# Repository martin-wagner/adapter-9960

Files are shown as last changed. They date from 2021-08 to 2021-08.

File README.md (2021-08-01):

# adapter-9960
Adapter for unobtainable nixie tube driver IC fairchild 9960 ( 960, 996079 ) to SN74414 / K155id1

Contains Kicad project, pdf schematic and gerber files for ordering at your pcb service of choise. Added some other more or less useful stuff to the panel to optimeze for the common 10x10cm pcb manufacturing services. Should fit as direct replacement if pcb is not too densly packed.

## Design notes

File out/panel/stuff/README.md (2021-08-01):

# SMT Breakout Boards

Some small adapter boards to help with prototyping SMT packages on a breadboard.

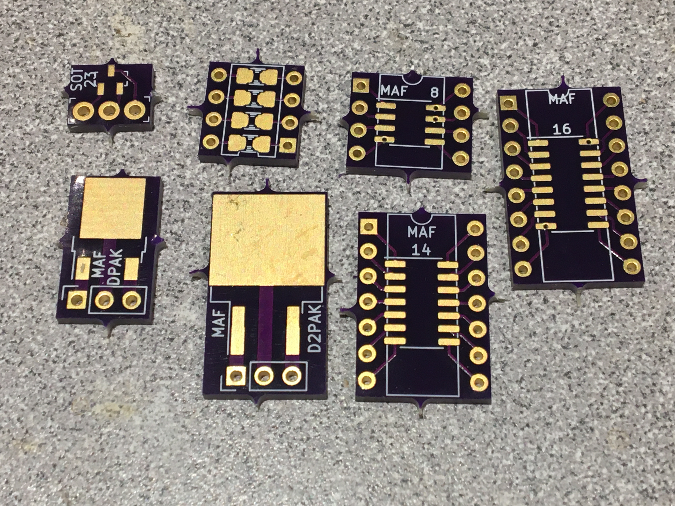
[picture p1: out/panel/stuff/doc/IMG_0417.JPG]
boards


## Design

I used KiCad to draw these.

Usually you would start with a schematic and a symbol and then lay out the PCB.

In this case I just opened the PCBNew application and ad-hoc added the footprints and then drew traces to wire them up.

## Supported Packages

* [SOIC](https://en.wikipedia.org/wiki/Small_outline_integrated_circuit)
  * 8
  * 14
  * 16
* [SOT-23](https://en.wikipedia.org/wiki/Small-outline_transistor)
  * 3
  * 5
* DPAK / [TO-252](https://en.wikipedia.org/wiki/TO-252)
* D2PAK / [TO-263](https://en.wikipedia.org/wiki/TO-263)
* Discrete 0406 / 0603 / 0806 / 1204 packages in a DIP carrier footprint
  * x4
  * x7

I will add more footprints as I need them.

## Fabrication

I Used OSHPark to have these made. Mostly because I don't have a setup to make my own boards.

For convenience, I shared the uploaded board projects:

| Part | Link |
|:-----|:-----|
| SOIC-8  | https://oshpark.com/shared_projects/7HKL5QIy |
| SOIC-14 | https://oshpark.com/shared_projects/QcCbjX4y |
| SOIC-16 | https://oshpark.com/shared_projects/uA6pM7Gf |
| SOT-23  | https://oshpark.com/shared_projects/ge0wqWtr |
| SOT23-5 | https://oshpark.com/shared_projects/e4J13SY4 |
| SMD-6 | https://oshpark.com/shared_projects/h2nZ3u9U |
| TO-252 (DPAK) | https://oshpark.com/shared_projects/cjtZqxyG |
| TO-263 (D2PAK) | https://oshpark.com/shared_projects/tPH46DG8 |
| 0406/0603/0806/1204 x4 | https://oshpark.com/shared_projects/MdGxr2ob |
| 0406/0603/0806/1204 x7 | https://oshpark.com/shared_projects/SLZF8xvz |

> I am not affiliated by or sponsored by OSHPark.
> I just am really happy with the kind of service they provide.

## Assembly

These steps assume you have

* A fine point soldering iron
* Fine electronic solder - I have 22 gauge
* Solder flux.

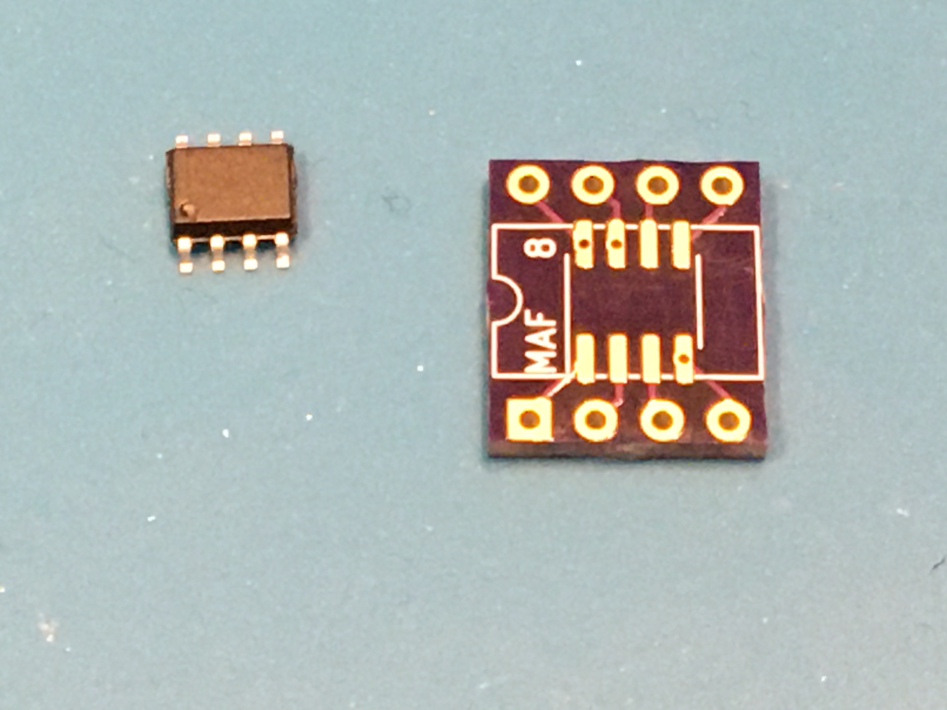
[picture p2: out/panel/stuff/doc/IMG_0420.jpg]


Start by soldering the SMT device to the PCB

* Use as fine of a tip of a soldering iron as you can

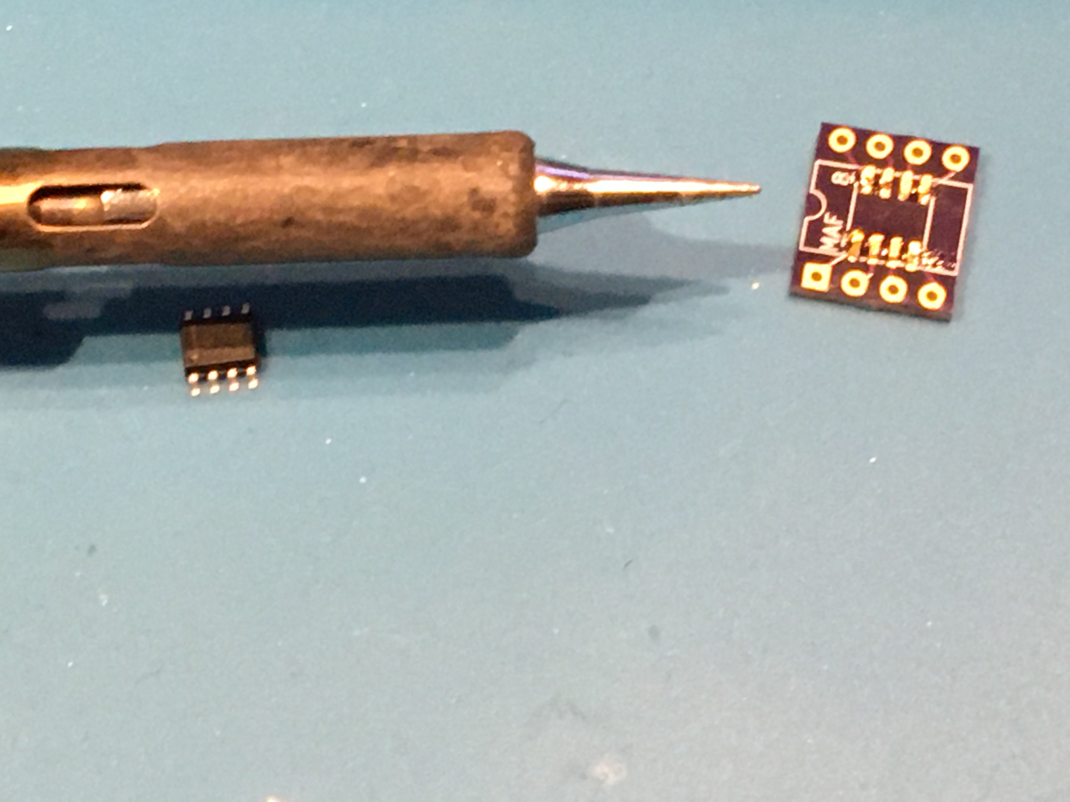
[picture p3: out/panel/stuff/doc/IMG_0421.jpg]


> I have a hot air solder station. I use a fine point solder iron here, as this is more likely what most people would have.

* Use a bit of solder flux across all the pads.

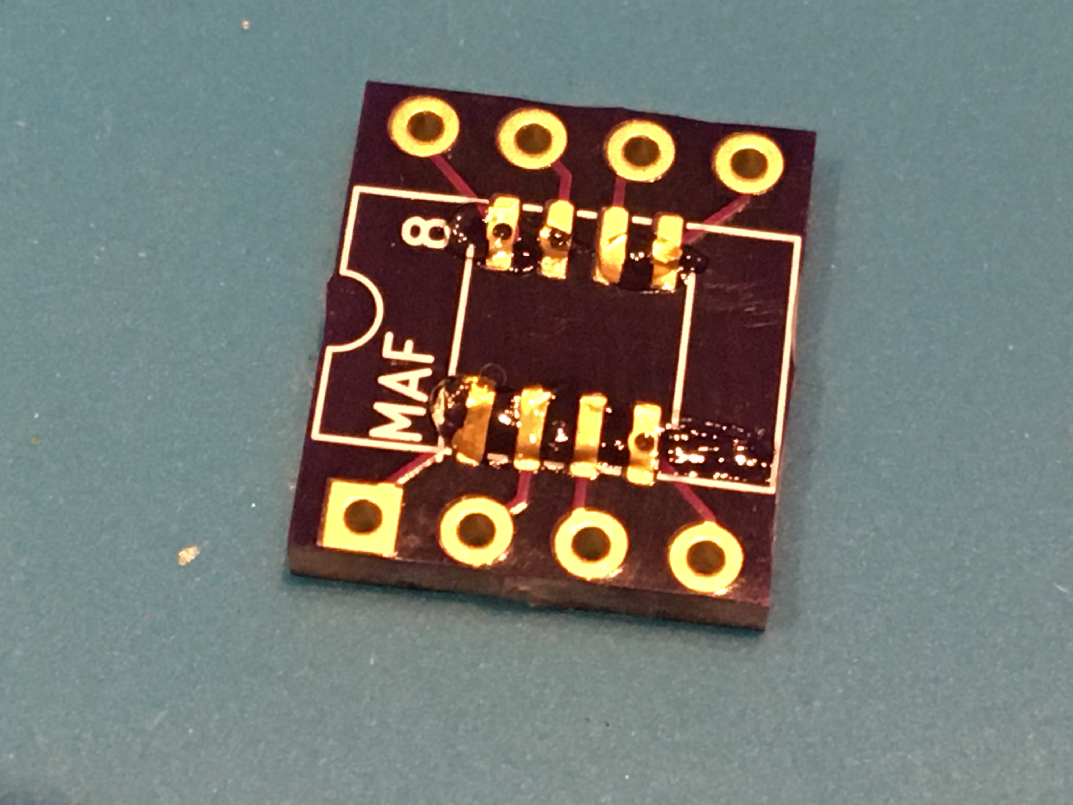
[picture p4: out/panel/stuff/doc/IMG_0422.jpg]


* Orient the package over the pads

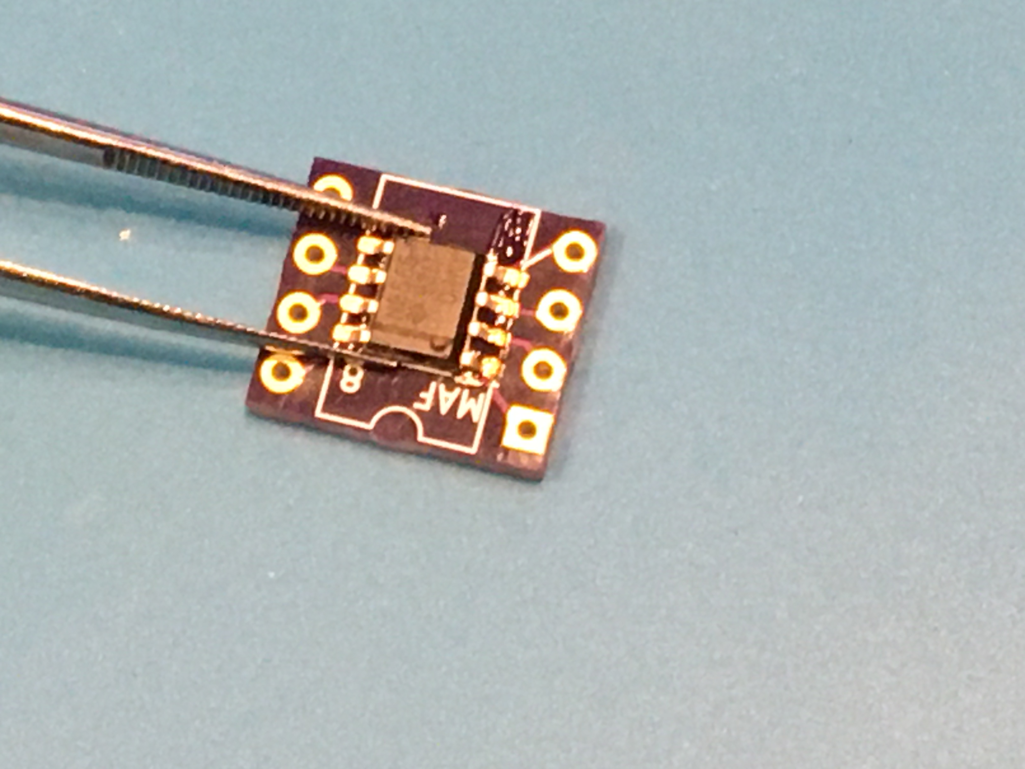
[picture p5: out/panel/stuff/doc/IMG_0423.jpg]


> I like to use a pair of tweezers

* Tack one of the pins with a bit of solder loosely.

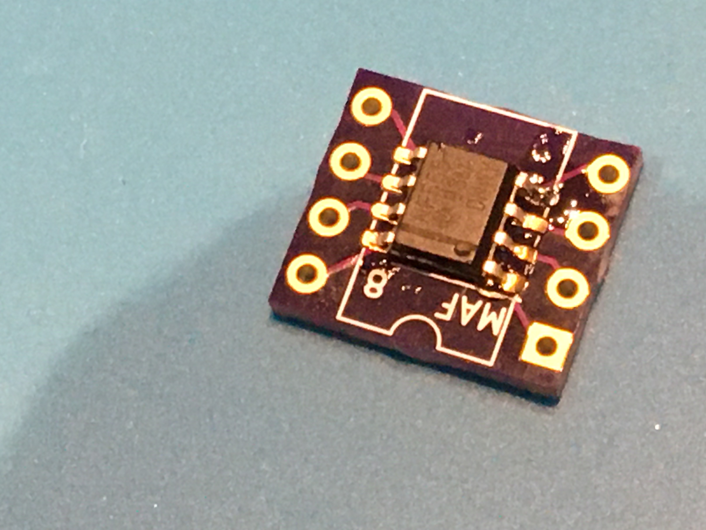
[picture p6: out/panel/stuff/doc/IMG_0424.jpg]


* Make sure the package is still lined up. If it is not. Reheat the pad we tacked it with, use tweezers to nudge the package until it is aligned.

> This is the hard part and takes practise.

* Drag a bit of solder across the pins

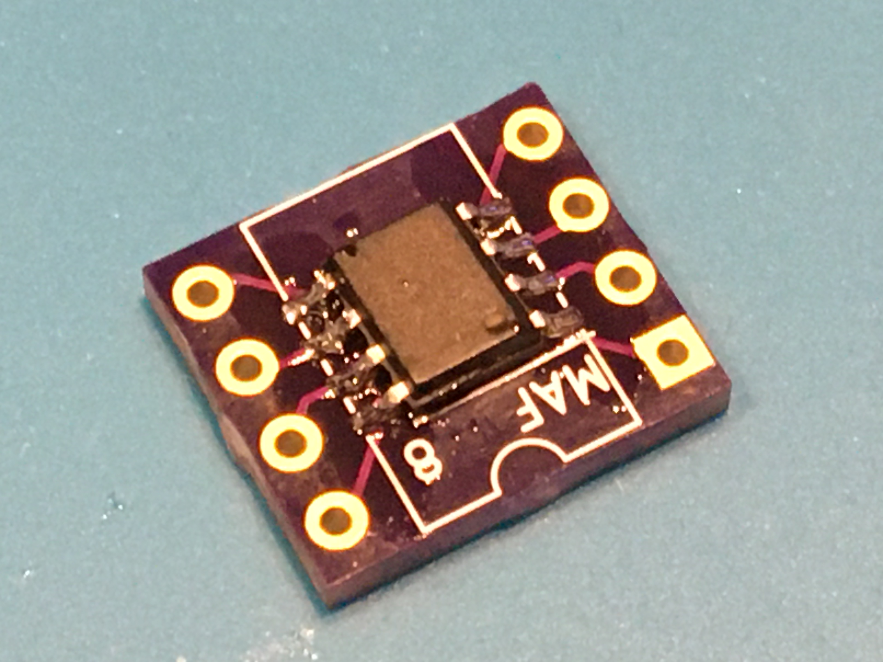
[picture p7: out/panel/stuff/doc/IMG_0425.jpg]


> This part is fun. The solder mask prevents the solder from sticking between the pads. The flux helps the solder to flow evenly over each pin.
> We want to use as little solder as possible here.

* Clean the extra solder flux off with a bit of rubbing alcohol and a q-tip or small sponge.

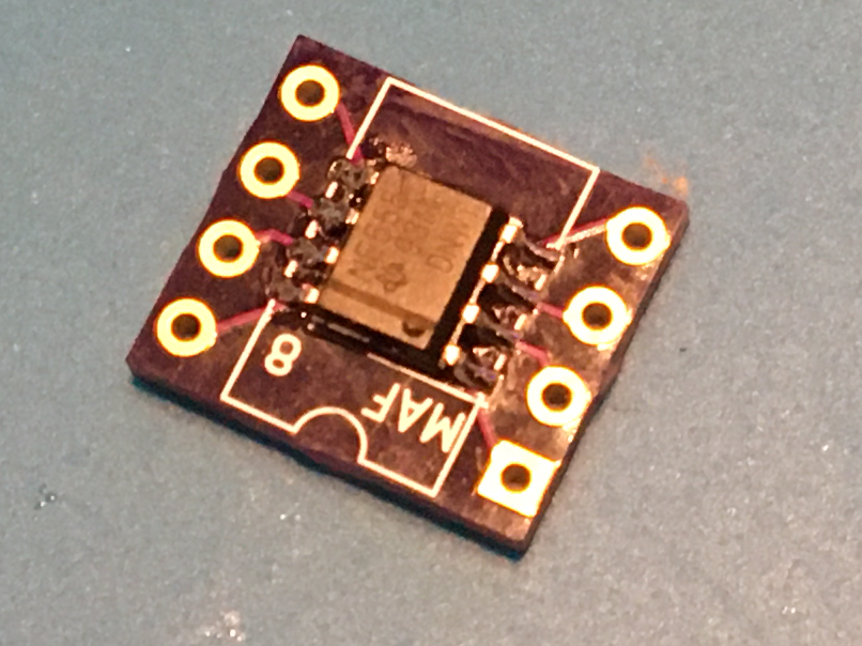
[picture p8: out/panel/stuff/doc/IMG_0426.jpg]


> If your device is static sensitive, work on a grounded or ESD safe surface.

* (Optional) : Where applicable, if you would like a decoupling capacitor, solder the 0603 package capacitor to the back

* Cut stock pin headers as needed.

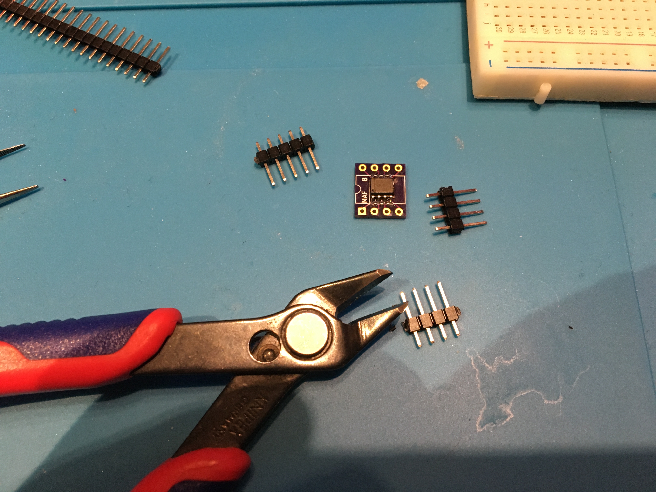
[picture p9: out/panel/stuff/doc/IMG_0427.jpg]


* Dry fit place the headers into the holes. Test alignment with a proto board or breadboard.

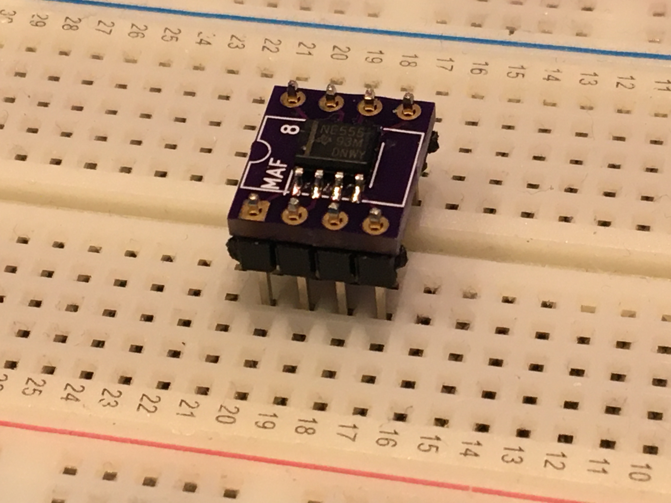
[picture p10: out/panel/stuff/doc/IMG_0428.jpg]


> But do not solder with a lot of heat on the breadboard, it migh melt the breadboard socket guides.

* Solder the pins all the way.

And then the final result:

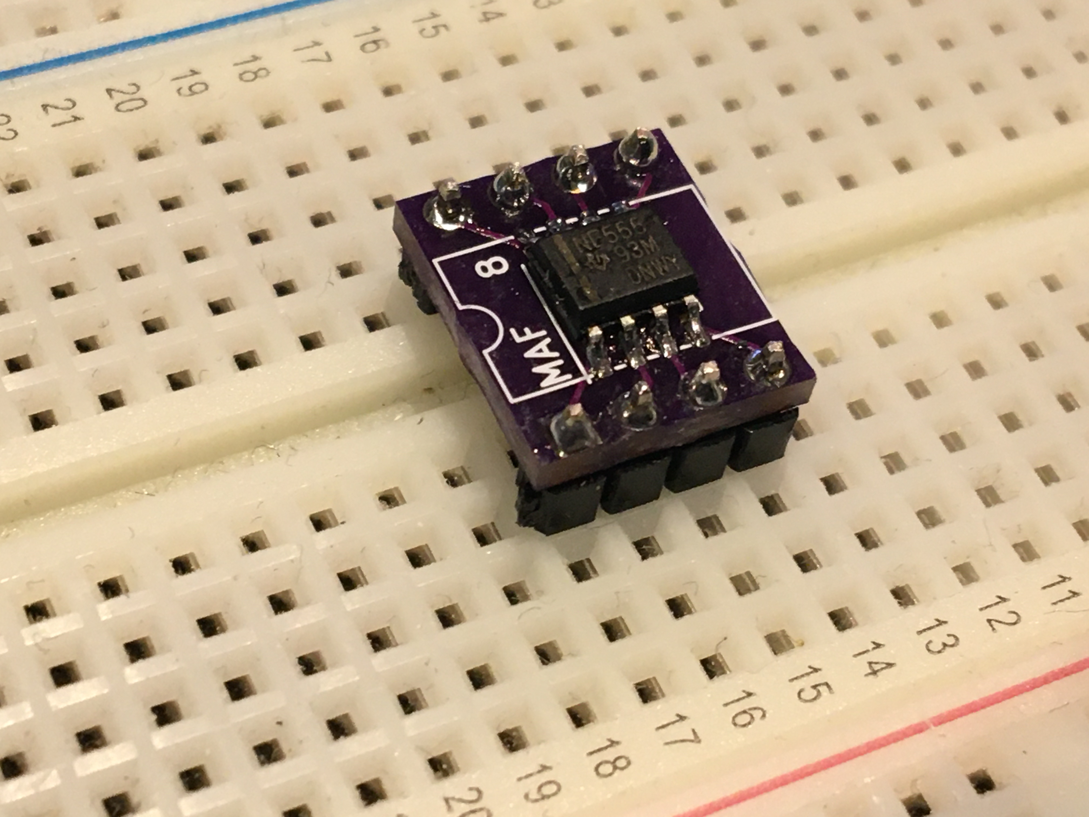
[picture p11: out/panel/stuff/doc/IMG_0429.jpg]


It is the similar idea for the other packages, just with more or different pins really.

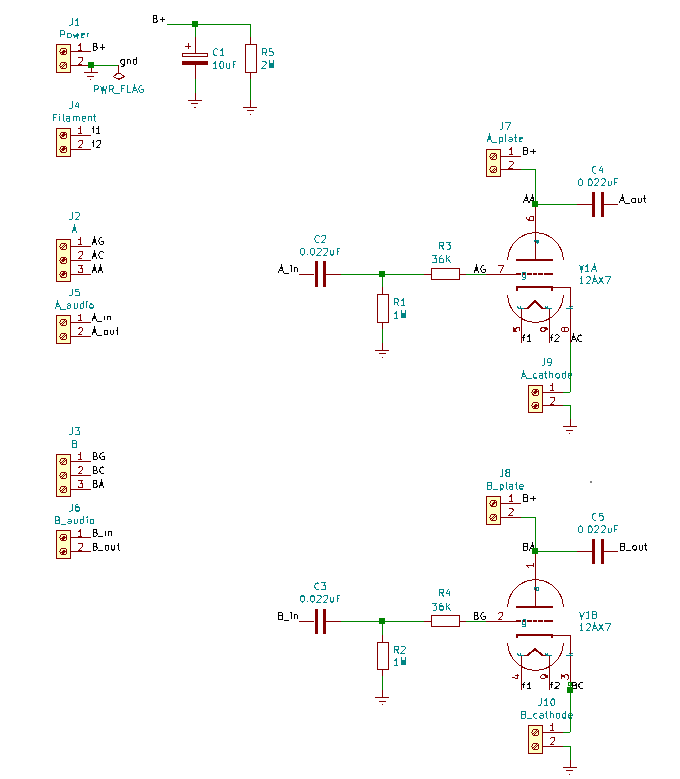
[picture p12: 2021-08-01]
out/panel/stuff/VT9-PT/schematic_v1.png

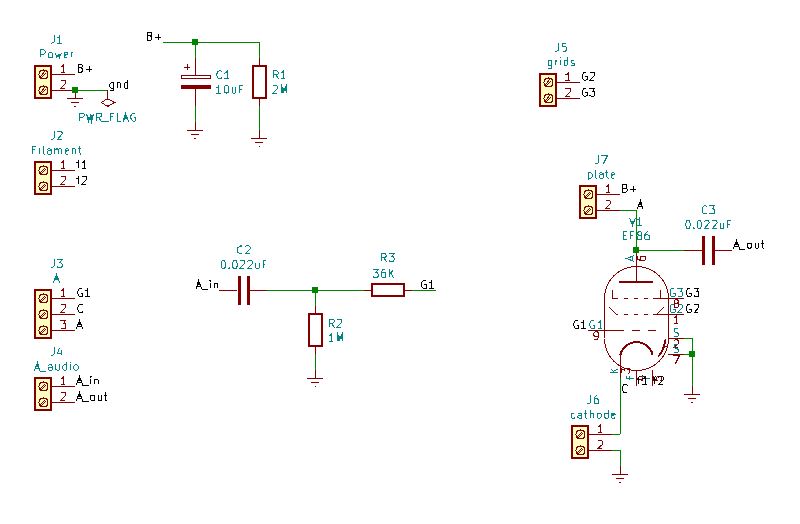
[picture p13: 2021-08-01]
out/panel/stuff/VT9-PT/ef86_schematic_v1.png

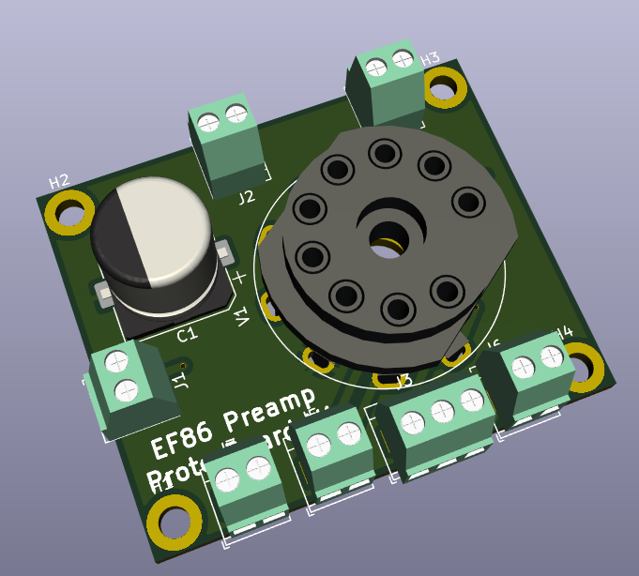
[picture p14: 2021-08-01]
out/panel/stuff/VT9-PT/ef86_board_v1.png

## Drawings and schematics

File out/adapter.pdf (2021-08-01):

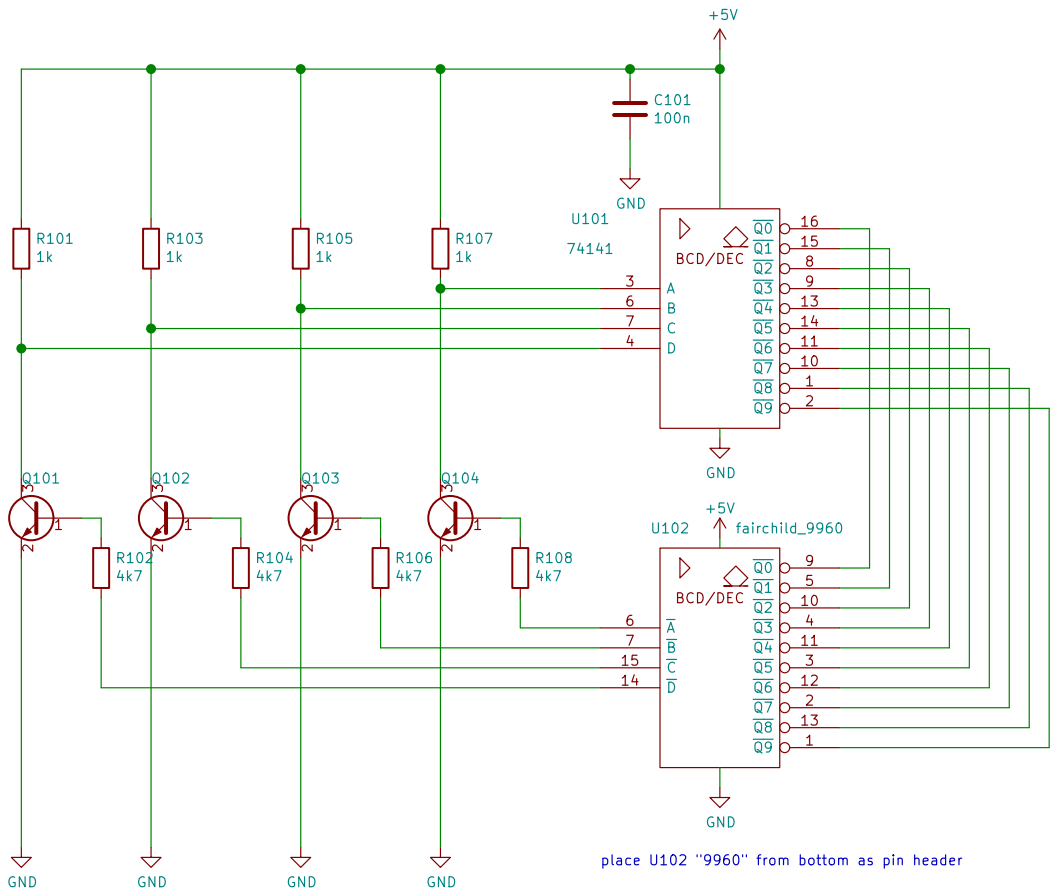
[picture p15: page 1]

place U102 "9960" from bottom as pin header

Adaptor BCD to decimal decoder Fairchild DTL 9960, 960, 996079 to SN74141

File: adapter.sch Sheet: / Martin Wagner DL2WAG

Id: 1/1 Title: Adaptor Fairchild 9960

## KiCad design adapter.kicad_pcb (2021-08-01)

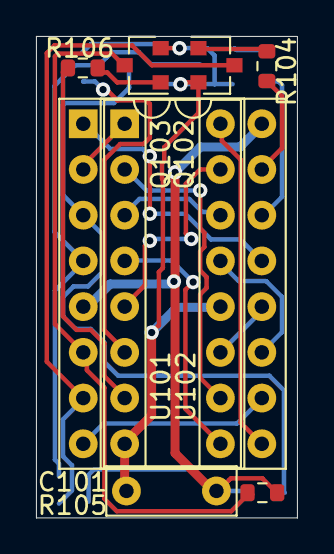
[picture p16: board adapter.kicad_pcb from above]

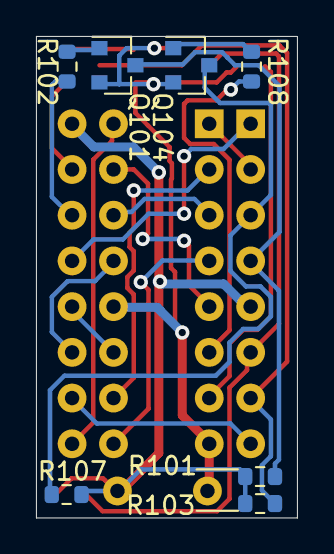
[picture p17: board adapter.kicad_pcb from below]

Board: 2 copper layers, 14.5 x 26.8 mm, 15 parts (7 on the bottom side), 24 nets.

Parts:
C101: 100n; C_Disc_D7.0mm_W2.5mm_P5.00mm
Q101, Q102, Q103, Q104: Q_NPN_BEC; SOT-23
R101, R102, R103, R104, R105, R106, R107, R108: 1k; R_0603_1608Metric
U101: 74141; DIP-16_W7.62mm_Socket
U102: fairchild_9960; DIP-16_W7.62mm_Socket

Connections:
+5V: C101.1, R101.2, R103.2, R105.2, R107.2, U101.5, U102.16
GND: C101.2, Q101.2, Q102.2, Q103.2, Q104.2, U101.12, U102.8
unnamed: Q101.1, R102.2
unnamed: Q101.3, R101.1, U101.4
unnamed: Q102.1, R104.2
unnamed: Q102.3, R103.1, U101.7
unnamed: Q103.1, R106.2
unnamed: Q103.3, R105.1, U101.6
unnamed: Q104.1, R108.2
unnamed: Q104.3, R107.1, U101.3
unnamed: R102.1, U102.14
unnamed: R104.1, U102.15
unnamed: R106.1, U102.7
unnamed: R108.1, U102.6
unnamed: U101.1, U102.13
unnamed: U101.2, U102.1
unnamed: U101.8, U102.10
unnamed: U101.9, U102.4
unnamed: U101.10, U102.2
unnamed: U101.11, U102.12
unnamed: U101.13, U102.11
unnamed: U101.14, U102.3
unnamed: U101.15, U102.5
unnamed: U101.16, U102.9

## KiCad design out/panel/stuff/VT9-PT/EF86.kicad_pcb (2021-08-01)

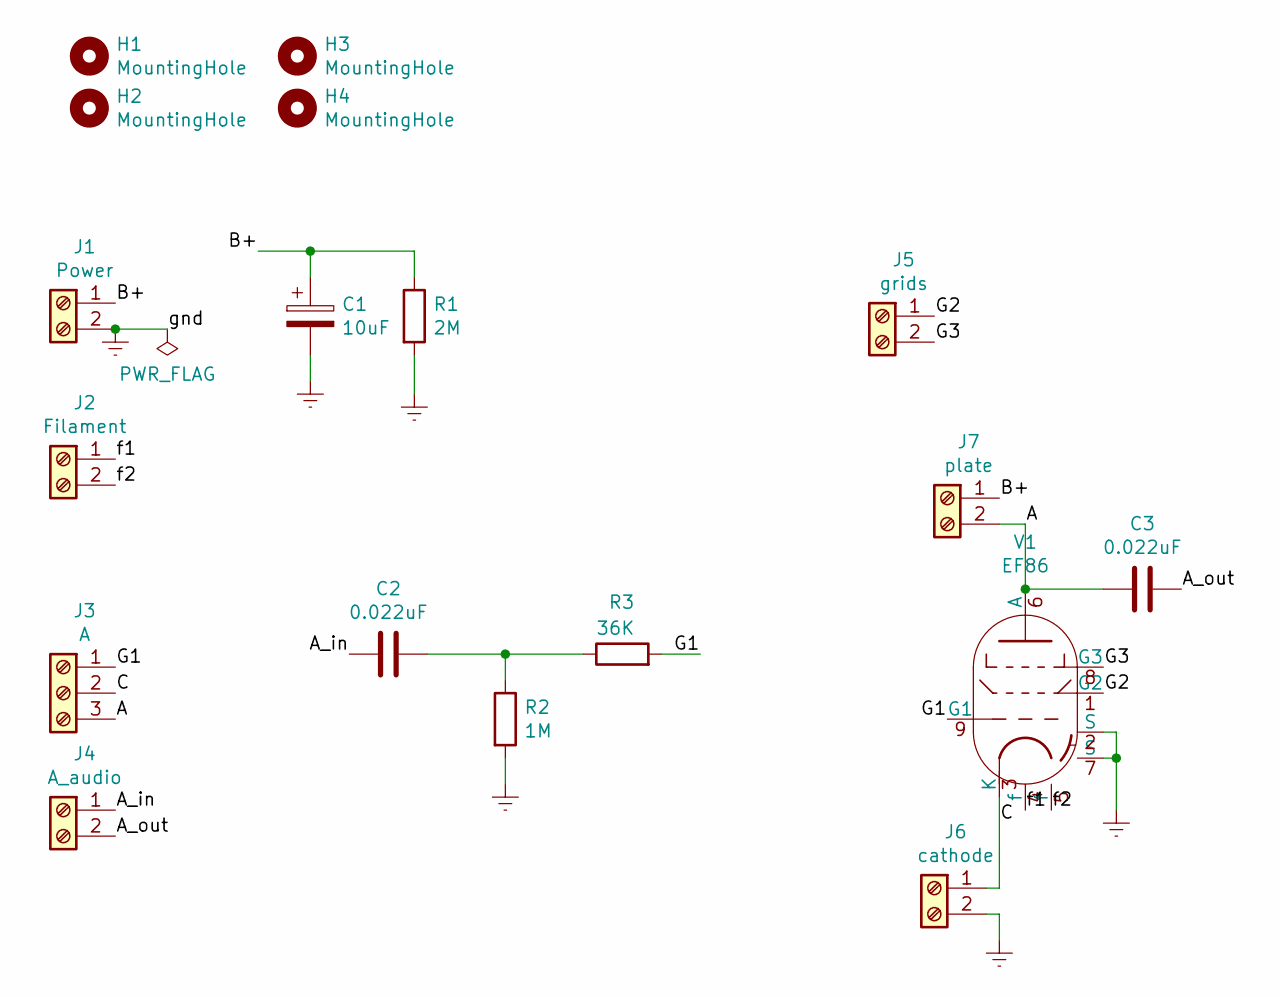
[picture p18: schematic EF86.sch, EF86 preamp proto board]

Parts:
C1: 10uF; CP_Elec_10x10.5
C2, C3: 0.022uF; C_1206_3216Metric
H1, H2, H3, H4: MountingHole; MountingHole_2.7mm_M2.5_DIN965_Pad
J1: Power; TerminalBlock_1x02_P2.54mm_Horizontal
J2: Filament; TerminalBlock_1x02_P2.54mm_Horizontal
J3: A; TerminalBlock_1x03_P2.54mm_Horizontal; Digi-Key_PN ED10562-ND
J4: A_audio; TerminalBlock_1x02_P2.54mm_Horizontal
J5: grids; TerminalBlock_1x02_P2.54mm_Horizontal
J6: cathode; TerminalBlock_1x02_P2.54mm_Horizontal
J7: plate; TerminalBlock_1x02_P2.54mm_Horizontal
R1: 2M; R_1206_3216Metric
R2: 1M; R_1206_3216Metric
R3: 36K; R_1206_3216Metric
V1: EF86; VT9-PT

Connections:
/A: C3.2, J3.3, J7.2, V1.6 (A)
/A_in: C2.2, J4.1
/A_out: C3.1, J4.2
/B+: C1.1, J1.1, J7.1, R1.1
/C: J3.2, J6.1, V1.3 (K)
/G1: J3.1, R3.2, V1.9 (G1)
/G2: J5.1, V1.1 (G2)
/G3: J5.2, V1.8 (G3)
/f1: J2.1, V1.4 (f)
/f2: J2.2, V1.5 (f)
Earth: C1.2, J1.2, J6.2, R1.2, R2.2, V1.2 (S), V1.7 (S)
unnamed: C2.1, R2.1, R3.1

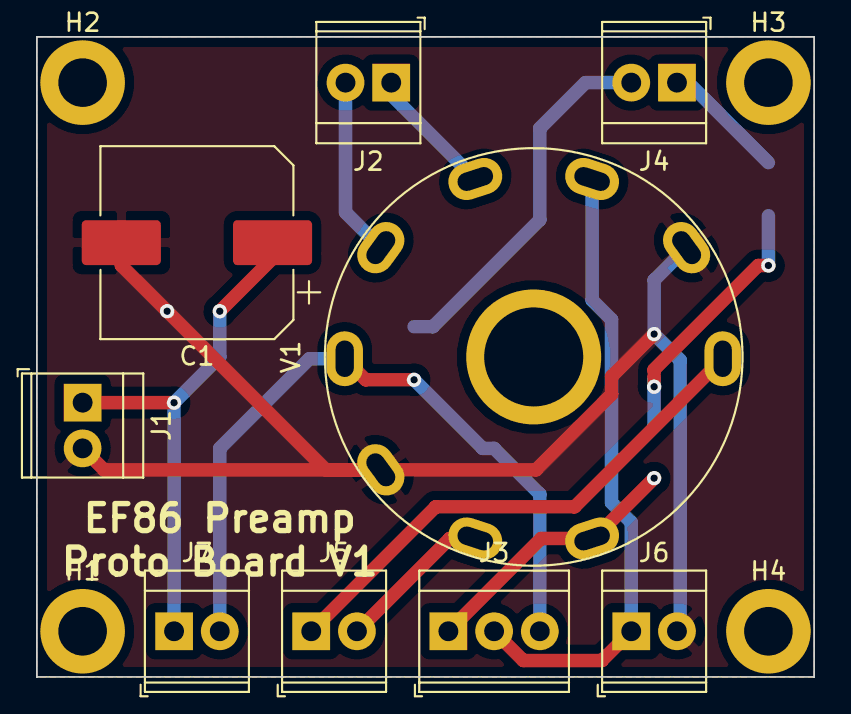
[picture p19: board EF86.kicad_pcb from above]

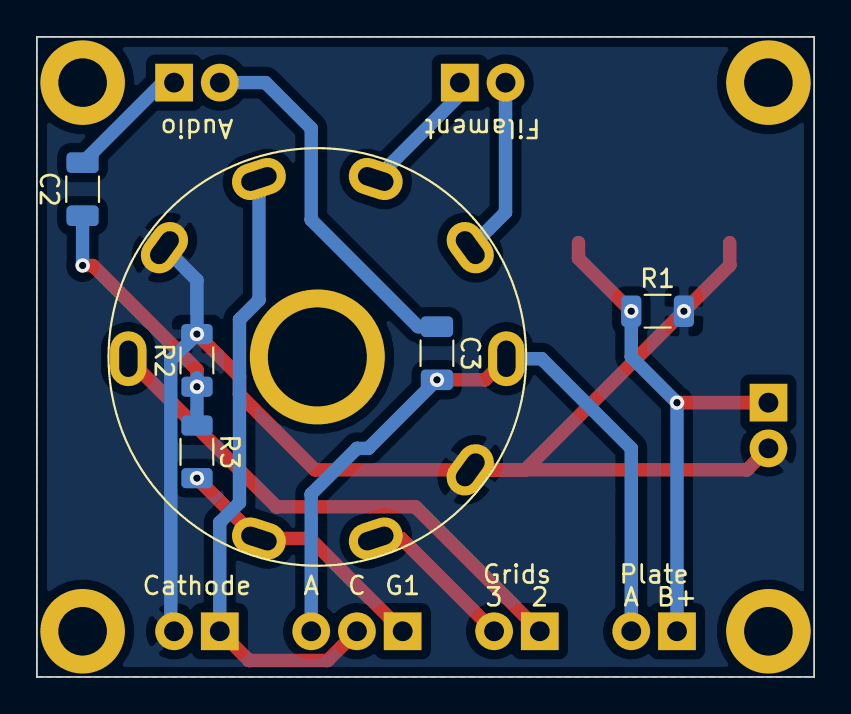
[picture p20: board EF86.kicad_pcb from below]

Board: 2 copper layers, 43.2 x 35.6 mm, 18 parts (5 on the bottom side), 12 nets.

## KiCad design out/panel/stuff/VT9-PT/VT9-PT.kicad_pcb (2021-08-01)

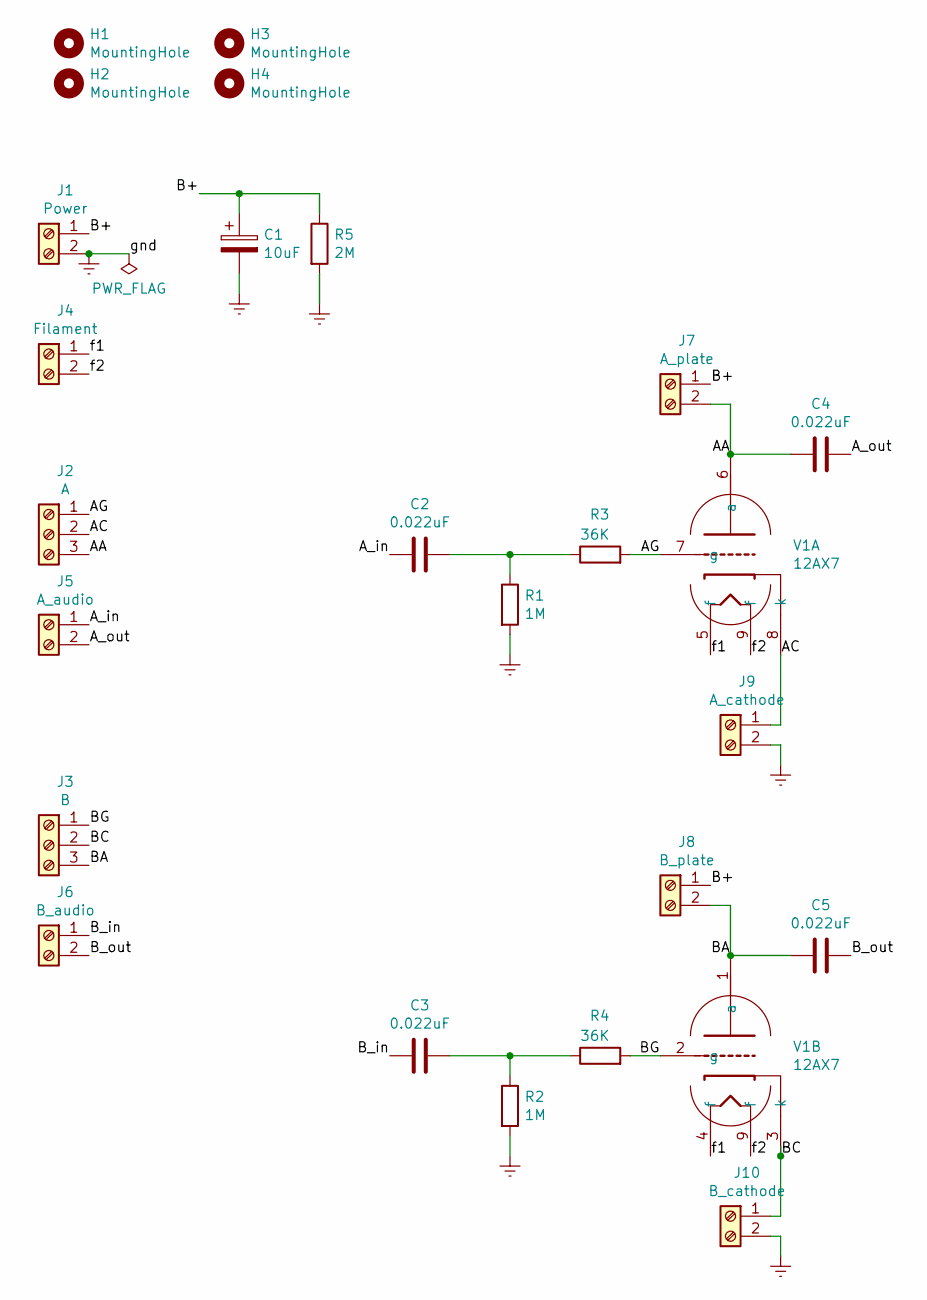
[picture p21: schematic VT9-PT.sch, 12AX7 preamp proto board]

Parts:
C1: 10uF; CP_Elec_10x10.5
C2, C3, C4, C5: 0.022uF; C_1206_3216Metric
H1, H2, H3, H4: MountingHole; MountingHole_2.7mm_M2.5_DIN965_Pad
J1: Power; TerminalBlock_1x02_P2.54mm_Horizontal
J2: A; TerminalBlock_1x03_P2.54mm_Horizontal; Digi-Key_PN ED10562-ND
J3: B; TerminalBlock_1x03_P2.54mm_Horizontal; Digi-Key_PN ED10562-ND
J4: Filament; TerminalBlock_1x02_P2.54mm_Horizontal
J5: A_audio; TerminalBlock_1x02_P2.54mm_Horizontal
J6: B_audio; TerminalBlock_1x02_P2.54mm_Horizontal
J7: A_plate; TerminalBlock_1x02_P2.54mm_Horizontal
J8: B_plate; TerminalBlock_1x02_P2.54mm_Horizontal
J9: A_cathode; TerminalBlock_1x02_P2.54mm_Horizontal
J10: B_cathode; TerminalBlock_1x02_P2.54mm_Horizontal
R1, R2: 1M; R_1206_3216Metric
R3, R4: 36K; R_1206_3216Metric
R5: 2M; R_1206_3216Metric
V1: 12AX7; VT9-PT

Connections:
/AA: C4.2, J2.3, J7.2, V1.6 (a)
/AC: J2.2, J9.1, V1.8 (k)
/AG: J2.1, R3.2, V1.7 (g)
/A_in: C2.2, J5.1
/A_out: C4.1, J5.2
/B+: C1.1, J1.1, J7.1, J8.1, R5.1
/BA: C5.2, J3.3, J8.2, V1.1 (a)
/BC: J3.2, J10.1, V1.3 (k)
/BG: J3.1, R4.2, V1.2 (g)
/B_in: C3.2, J6.1
/B_out: C5.1, J6.2
/f1: J4.1, V1.4 (f), V1.5 (f)
/f2: J4.2, V1.9 (f)
Earth: C1.2, J1.2, J9.2, J10.2, R1.2, R2.2, R5.2
unnamed: C2.1, R1.1, R3.1
unnamed: C3.1, R2.1, R4.1

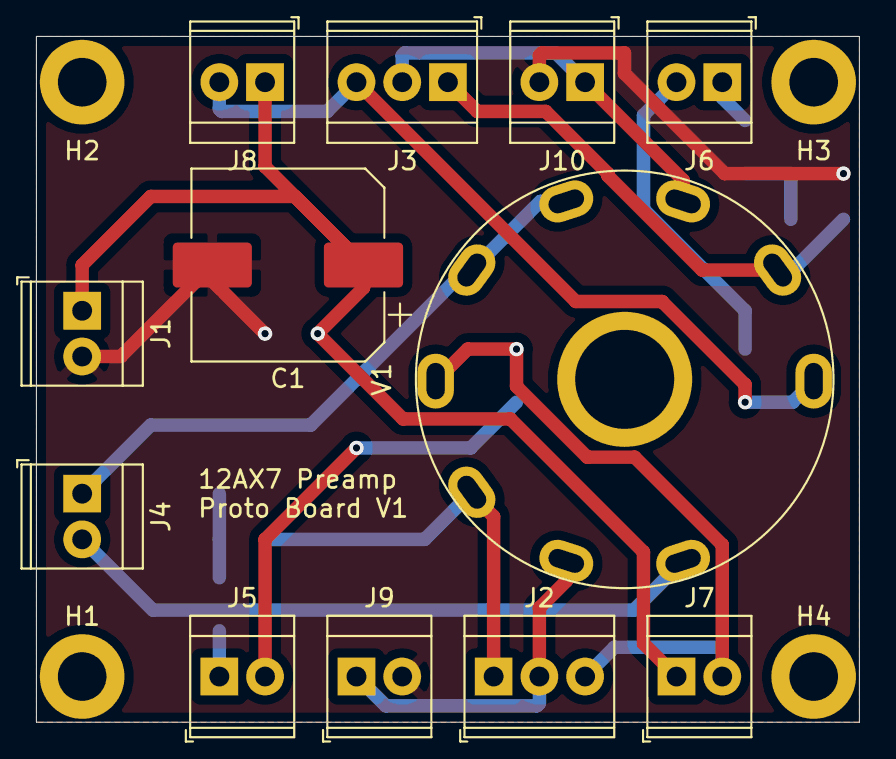
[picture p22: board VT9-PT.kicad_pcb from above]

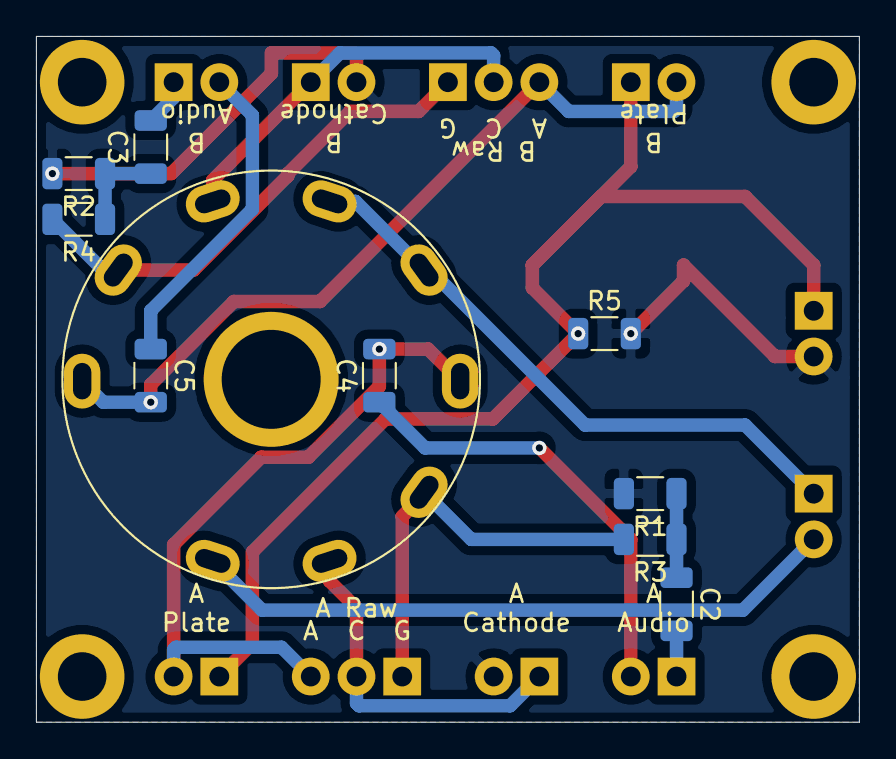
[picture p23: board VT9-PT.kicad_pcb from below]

Board: 2 copper layers, 45.7 x 38.1 mm, 25 parts (9 on the bottom side), 16 nets.
